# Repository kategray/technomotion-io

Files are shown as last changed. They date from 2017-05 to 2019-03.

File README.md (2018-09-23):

# Technomotion-IO

## Home of Tech-IO and the GHETT-iO

For documentation, see [https://ghett.io/](https://ghett.io/), or the
[docs/](docs/) folder.

This project is licensed under the [WTFPL 2.0](COPYING) license.  A license
is hereby granted to you to "just DO WHAT THE FUCK YOU WANT TO.".

This project is also available under the [MIT](COPYING) license.

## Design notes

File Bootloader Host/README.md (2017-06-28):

Bootloader host for updating GHETT-iO devices

CyUSB.dll is Copyright 2011, Cypress Semiconductor

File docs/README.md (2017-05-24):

# Technomotion IO Emulator

## Description
Dancing stage games are a popular form of entertainment in Japan, and in the United States.  This board provides I/O functionality for a simulated arcade environment.

## Background
### Hardware
Machines generally fall into three categories - four, five, and eight panel.

#### 4 Panel Machines (e.g. Dance Dance Revolution, In The Groove)
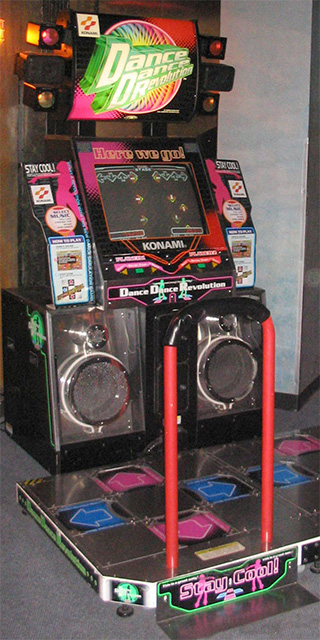
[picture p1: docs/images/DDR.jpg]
Dance Dance Revolution Machine


These games feature four arrows - Up,Down,Left,Right.  The center panel is usually non-functional, and is used as a place to stand.

#### 5 Panel Machines (e.g. Pump It Up)
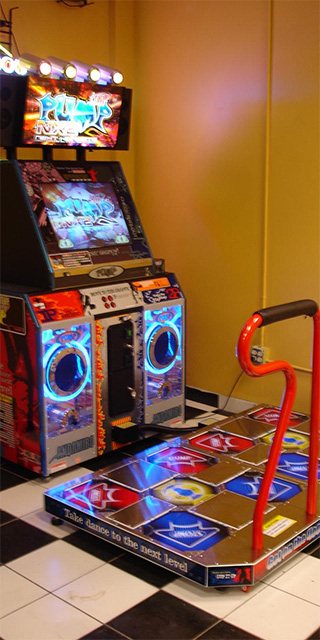
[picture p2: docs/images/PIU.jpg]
Pump It Up


Pump it up features 5 dance panels - a center panel and the 4 corners.  The center panel is functional, and players stand between the arrows when resting.

#### 8 Panel Machines (e.g. Technomotion)
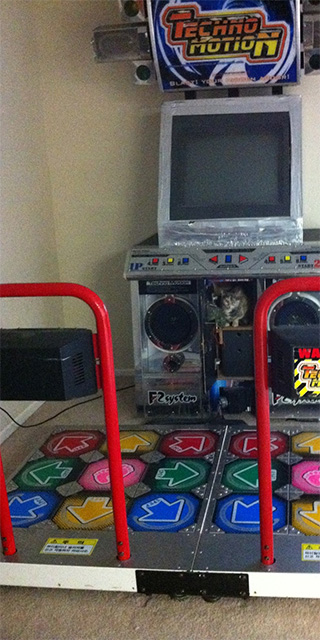
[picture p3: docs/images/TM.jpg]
TechnoMotion


TechnoMotion features a 9 panel stage, but lacks a 9 panel mode.  Instead, the game can be switched between 4 panel, 5 panel, and 8 panel (all panels except for the center), even while the game is playing.

### Emulation
Arcade machines (while new) typically cost $10,000 USD or more. They are difficult for people to use in their home due to the size and the weight.

StepMania is an open-source reimplementation of dancing stage games for home computers.  It features a flexible LUA-based scripting and theme engine, as well as support for emulation of the most popular play formats.

In general, dancing stage games follow a standard format.  A series of arrows is displayed on the screen, typically scrolling from bottom to top.  At the top of the screen a set of matching arrows are visible, and when the arrow at the top matches the arrow in the move list, the player is supposed to press the corresponding arrow.  Players receive points for proper presses, depending on how accurately their timing is.  Extra steps are generally not penalized.

### Hardware

#### Konami (Dance Dance Revolution)

Any discussion of Dancing games would be remiss if it did not start with Konami, the company largely responsible for the creation of the genre.

Konami is a Japanese entertainment company, and their Dance Dance Revolution game is highly influenced by the culture and environment which birthed it.  The game capitalized on the popularity of the J-Pop genre, as well as the popularity of English in Japan, leading to a game in which the text is mostly Japanese, but the dialog is all in English.  Songs are a fusion of Japanese and American songs, helping lead to the popularity of Japanese arcade machines in the US.

Being a Japanese game company, they developed for the popular systems of the time.  Working closely with Sony, they were able to adapt the processor from the popular PlayStation console to a custom PCB.  This allowed them to use largely the same game for home use and Arcade machines.  By producing a generic "playstation arcade version", they were able to keep the hardware largely the same (the System 573 platform), while producing I/O boards that could be used for different purposes.  Later versions of the arcade platform would simply put a Playstation 2 in an enclosure.

As a Japanese company, they tended to follow Japanese standards.  Their arcade machines follow the JAMMA (Japan Amusement Machine and Marketing Association) standards, and the Dance Dance Revolution machines are no exception.  JAMMA connectors are designed to permit arcade PCBs to easily move from one machine to another, and while the unique needs of the DDR machines (lights and cabinet outputs) necessitate additional connectors that make moving the PCB impossible, they still chose to follow the standard.

As is typical for arcade machines, JAMMA compliant power supplies feature +12v, +5v, and -5v rails.  +5v was chosen due to the use of CMOS logic signal voltage levels, and -5v is used in a few machines to drive op amps (generally for audio).  12v is used to drive lights, fans, etc., and reduces the line losses for the same wattage.

Inputs are active-low, which simplifies the handling and debouncing of inputs.  The input is brought high with the use of a pull-up resistor, and the normally open input is connected to ground.  A capacitor is used to keep the input high for a period of time after the switch is connected, and a Schmitt trigger serves to provide hysteris, leading to a very clean output.  Inverting Schmitt triggers are generally used to provide an active-high input to microcontrollers.

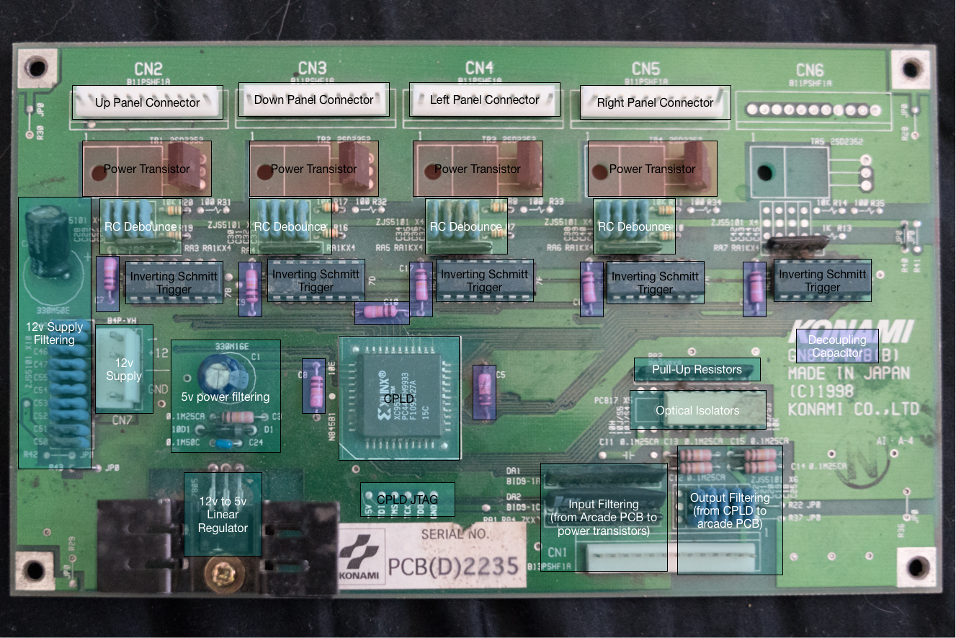
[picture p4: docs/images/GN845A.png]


Konami's design emphasized component reuse, and low EMI.  As such, they used a large number of 3 terminal EMI filters (ZJS5101), which combine the functions of both capacitors and inductors, providing an effective low-pass filter to reduce harmful RF interference.  The use of a linear voltage regulator, while less efficient, also served to avoid high speed switching noise.  Being a Japanese company, JST connectors were used.

The CPLD used (XC9536) provided for high-speed input handling.  Each panel contains 4 pressure-sensitive sensors, which are fed to Hex Schmitt Inverters.  The output from this is fed into the XC9536, which combines the inputs from each panel into a single output which is fed to the JAMMA harness.  Additionally, for testing, the CPLD can be placed into a mode where each sensor is individually addressable (to determine if sensors are stuck or failing to fire), and accessed via low speed RS232.  The use of the CPLD enables response times of several milliseconds, important for timing in rhythm-based games.  

Each panel has four inputs (one for each sensor), and an output (used to light the panel).  The IO board is designed to be extensible, and features support for an additional fifth input.  The output is driven using an NPN power transitor to switch the 12v supply.  

Signals from the stage PCB to the arcade PCB are optically isolated, cleaned up with a capacitor, and an EMI filter.  EMI coming from the system PCB to the stage PCB is less of an issue, and power surges more so.  As such, signals coming from the stage PCB are connected to two diode arrays (positive and negative) that serve as voltage clamps, protecting the NPN power transistor from voltages that exceed it's specifications by clamping them.

The board is responsible for its own conversion from 12v to 5v.  Although the system power supply is capable of producing a 5v supply, and linear voltage regulators are rather inefficient at this range, it provides a very clean and responsive supply.  Four separate capacitors are used (at different values) in order to ensure a very high speed response to power fluctuation.

#### Andamiro (Pump It Up)
As DDR was intended for use in JAMMA-Compatible arcades, as well as for the PlayStation, the game was largely limited to 4 direction inputs.  As such, Konami's design patents also extended to 4 directional inputs.

Pump It Up was built as a 5 panel game in part to get around the design patents.  By using diagonal arrows, and a center panel, they were able to avoid patent infringement.

#### Roxor Games (In The Groove)
Around 2004, Roxor Games came out with In The Groove, a game designed to adress the stagnation in the dance game marketplace.  Roxor contacted the authors of the open-source StepMania game, and were able to get it relicensed.  They partnered with Andamiro to produce a line of arcade cabinets that featured StepMania in a 4 panel configuration, with new songs and features.

Additionally, they produced a line of upgrade kits for existing Dance Dance Revolution arcade machines.  This led to a lawsuit for infringement of design patents that ultimately bankrupted them and led to a settlement in which Konamy received all rights to the In The Groove intellectual property.

The ITG-IO, unlike the hardware produced by Konami is designed to be cheap.  By using commodity desktop computers, they were able to position themselves as a very low cost upgrade.  RF emissions were high, and the lack of a common ground between the PC and the arcade power supply would often lead to problems, but for arcade owners facing dwindling returns on their hardware, it was a cost-effective solution.

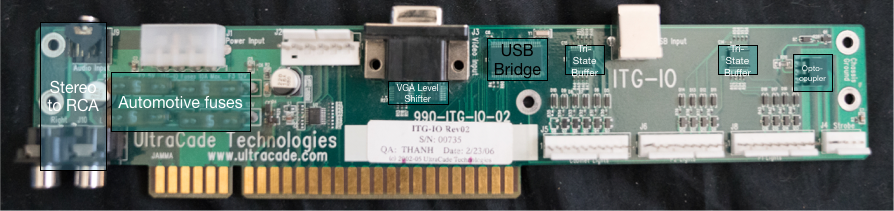
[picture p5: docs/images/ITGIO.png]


Roxor partnered with UltraCade Technologies to produce an IO board that permitted the adaptation of standard PCs to arcade machines.  It features a single optically-isolated output (to drive the neon lights), and the smallest possible number of inputs required.  As such, it ignores the second coin counter, coin lock functionality, buttons 1 and 4 of player input, etc.  Service and Test are combined into a single input.  Only VGA is supported, as the translation is more straightforward - 0.7v PC levels are amplified to 5v arcade levels, and the ITG-IO combines the separate RGB component sync signals into a single composite sync (as required by the JAMMA specification).

The ITG-IO does low-side switching, tristating the outputs with field effect transistors.  It features two USB endpoints, and it's low number of inputs and outputs allows packets to be 2 bytes in length.

Audio is handled by a simple passthrough 1/8 inch stereo to RCA adapter, intended for use with the DDR cabinet's audio amplifier.  Inputs come from the JAMMA connector, and outputs go to dedicated output connectors.

## Board Purpose

There are plenty of hardware solutions at present for getting four panel input to PC.  PS2 dance pads are widely available, along with a plethora of PS2 to USB adapters.  There are even a few options for output control, with devices like the Minimaid making it possible to replicate the functionality of the ITG-IO in placing a standard PC into a standard DDR cabinet.

Additionally, there are solutions out there for 5 and 8 (or 9) panel inputs.  Precision Dance Pads manufacturers dance pads in 4, 5, 6, or 9 panel configurations.

Unfortunately, where these solutions tend to fall short is outputs.  If someone wishes to build their own arcade machine, they are limited in the number of outputs they can have, and their ability to drive the lights on a cabinet, and in the pad.

The Technomotion IO emulater (Tek-IO) is designed to solve these issues.

## Theory of operation
Modern microcontrollers have significantly more analog IO functionality than previous generation chips.  The Cypress Programmable System on Chip (PSoC), for example, has the ability to do high-fidelity, adjustable PWM and software-defined debouncing.

Tek-IO is designed to handle all of the inputs and outputs necessary to construct any kind of dance control scheme.  It features the following benefits compared to existing solutions:

* Configurable analog I/O permits games (or players) to adjust the sensitivity
* Per-sensor configuration, permitting automatic adaptation to worn pads
* Automatic compensation for stuck or low-responsive pads
* Able to drive modern tricolor LEDs, permitting pads to change color depending on game mode or settings
* Permits the use of colored LEDs for cabinet lights and buttons
* Supports the use of multiple coin inputs (for example, a bill validator and a coin acceptor)
* Supports separate service, and courtesy credit input (useful for hardwired keyed momentary switches)
* Supports five buttons per player, allowing the use of DDR controls (left, right, start), DDR X (UDLR, Center), Technomotion (4 panel, 5 panel, 8 panel, Select, Start) and In The Groove (Left, Right, Up, Down).
* Programmable firmware permits the board to be reconfigured to different control schemes
* Implementation of the HID gamepad protocol enables easier integration
* A single board handles both stages, avoiding the need for separate power supplies
* Higher efficiency power supply reduces heat, and prolongs component life
* Ability to read individual sensors (using a propreitary interface)

Tek-IO presents itself to the operating system as a composite device with two separate 16-button joysticks, as well as offering USB endpoints for light control.  The use of two separate joysticks avoids issue with older versions of Linux experiencing memory corruption issues when using HID gamepads with more than 16 buttons.

## Inputs (Default configuration)
| Input | Description | Input |
| --- | --- | --- |
| P1 U, D, L, R | Player 1 Pad Up, Down, Left, Right | J1 B1-4  |
| P1 UL, UR, LL, LR | Player 1 Corners: UpperLeft, UpperRight, LowerLeft, LowerRight | J1 B5-8  |
| P1 Panel U, D, L, R | Player 1 Cabinet Up, Down, Left, Right | J1 B9-12 |
| P1 Center | Player 1 Pad Center panel | J1 B13 |
| P1 Panel Start | Player 1 Cabinet Start Button | J1 B14 |
| Coin 1 | First coin acceptor | J1 B15 |
| Service | Arcade machine service mode | J1 B16 |
| P2 U, D, L, R | Player 2 Pad Up, Down, Left, Right | J2 B1-4  |
| P2 UL, UR, LL, LR | Player 2 Corners: UpperLeft, UpperRight, LowerLeft, LowerRight | J2 B5-8  |
| P2 Panel U, D, L, R | Player 2 Cabinet Up, Down, Left, Right | J2 B9-12 |
| P1 Center | Player 1 Pad Center panel | J1 B13 |
| P2 Panel Start | Player 2 Cabinet Start Button | J2 B14 |
| Coin 2 | First coin acceptor | J2 B15 |
| Courtesy Credit | Arcade machine courtesy credit | J2 B16 |

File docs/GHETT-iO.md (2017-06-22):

# GHETT-iO Input/Output board

## Description
The GHETT-iO ("Ghetto IO") board is the easiest way to get input from a dance pad to a computer.  It is based on the [CY8CKIT-059][] PSoC prototyping kit.

## Philosophy
There are a variety of I/O solutions available for dance machines, however, it
can be difficult (and expensive) to replace failed parts.  Many of the boards are
designed to work only in an arcade cabinet; they rely upon external power supplies to
function.

The Cypress PSoC 5LP is a modern microcontroller with Full-Speed USB support, 
programmable logic capabilities, and a fast clock speed.  It's ARM-based, and has
a free manufacturer-supported toolchain [PSoC Creator][] available to download.

The company that produces the PSoC line of chips, [Cypress Semiconductor][] has made
available a $10 prototyping kit.  This kit includes a detachable programmer, and 
approximately 44 usable I/O pins (depending on configuration).  As the PSoC contains
internal input protection (diode clamps), as well as configurable pull-ups and pull-
downs, it is possible to handle all of the IO required for a standard DDR pad with
a single chip.

To assemble a GHETT-iO, one need only the kit from Cypress, reasonable soldering
equipment and skills, and the appropriate headers (if any).  The use of the standard
0.1 inch pitch and a DIP-style layout ensures that the board is directly compatible
with both breadboards and the DDR connectors.

The GHETT-iO is easy to assemble, and open source.  This should help ensure avail-
ability for the foreseeable future.

## Photos
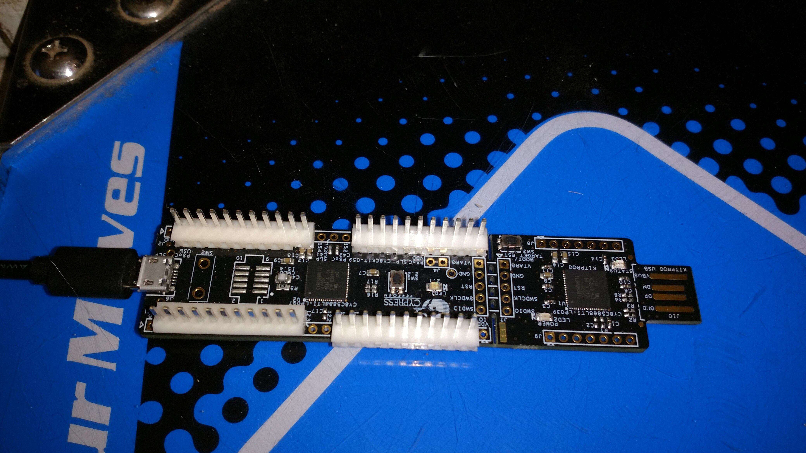
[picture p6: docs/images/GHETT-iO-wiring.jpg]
Connected GHETT-iO

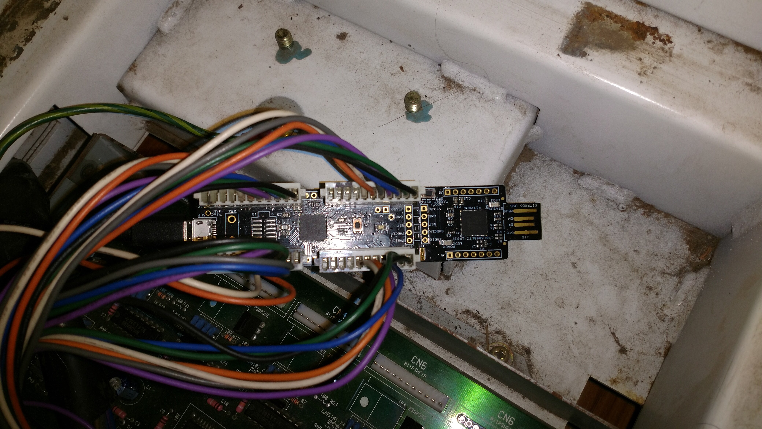
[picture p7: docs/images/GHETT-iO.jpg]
Bare GHETT-iO


[CY8CKIT-059]: http://www.cypress.com/documentation/development-kitsboards/cy8ckit-059-psoc-5lp-prototyping-kit-onboard-programmer-and

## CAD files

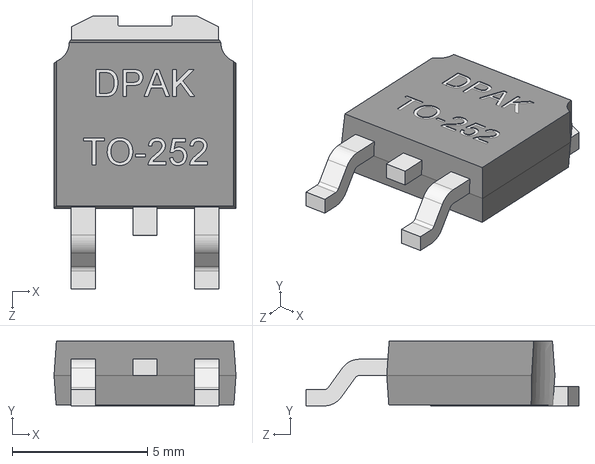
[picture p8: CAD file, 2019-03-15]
Light Board/3d/DPAK_TO-252AA.step
6.73 x 2.40 x 10.1 mm

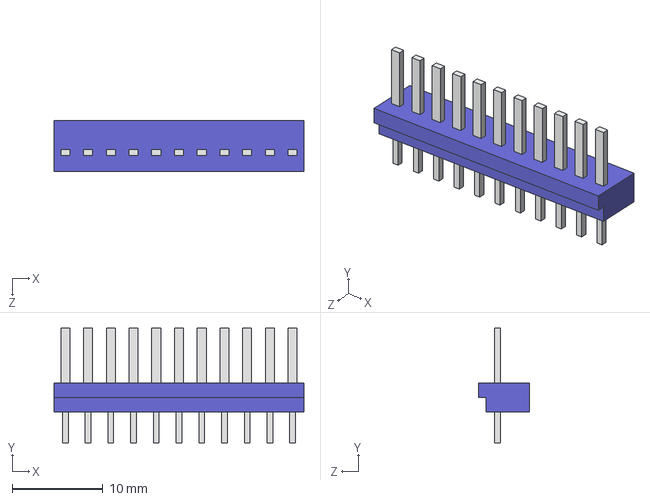
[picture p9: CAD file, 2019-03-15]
Light Board/3d/B11P-SHF-1AA.STEP
27.5 x 12.6 x 5.60 mm

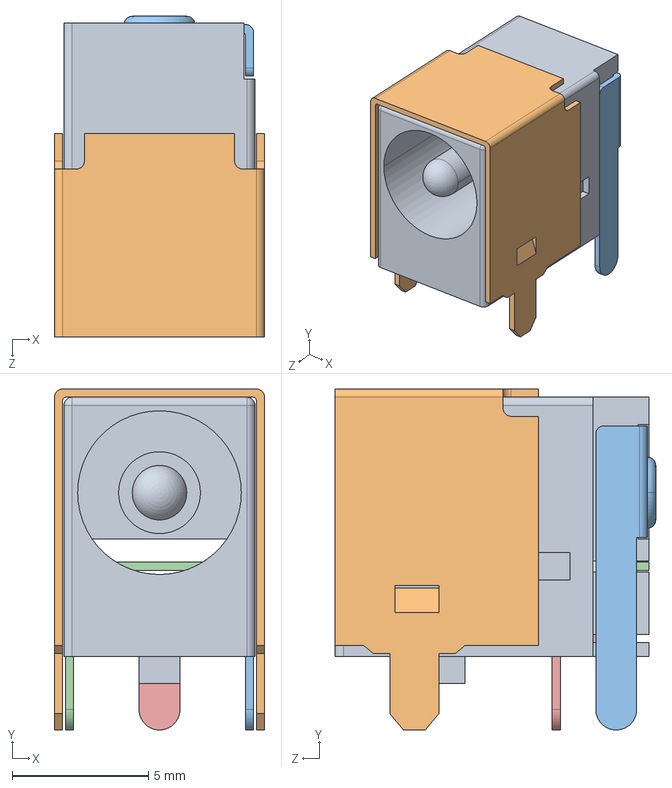
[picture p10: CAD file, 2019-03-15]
Light Board/3d/CUI_PJ-047AH.step
7.70 x 12.5 x 11.8 mm

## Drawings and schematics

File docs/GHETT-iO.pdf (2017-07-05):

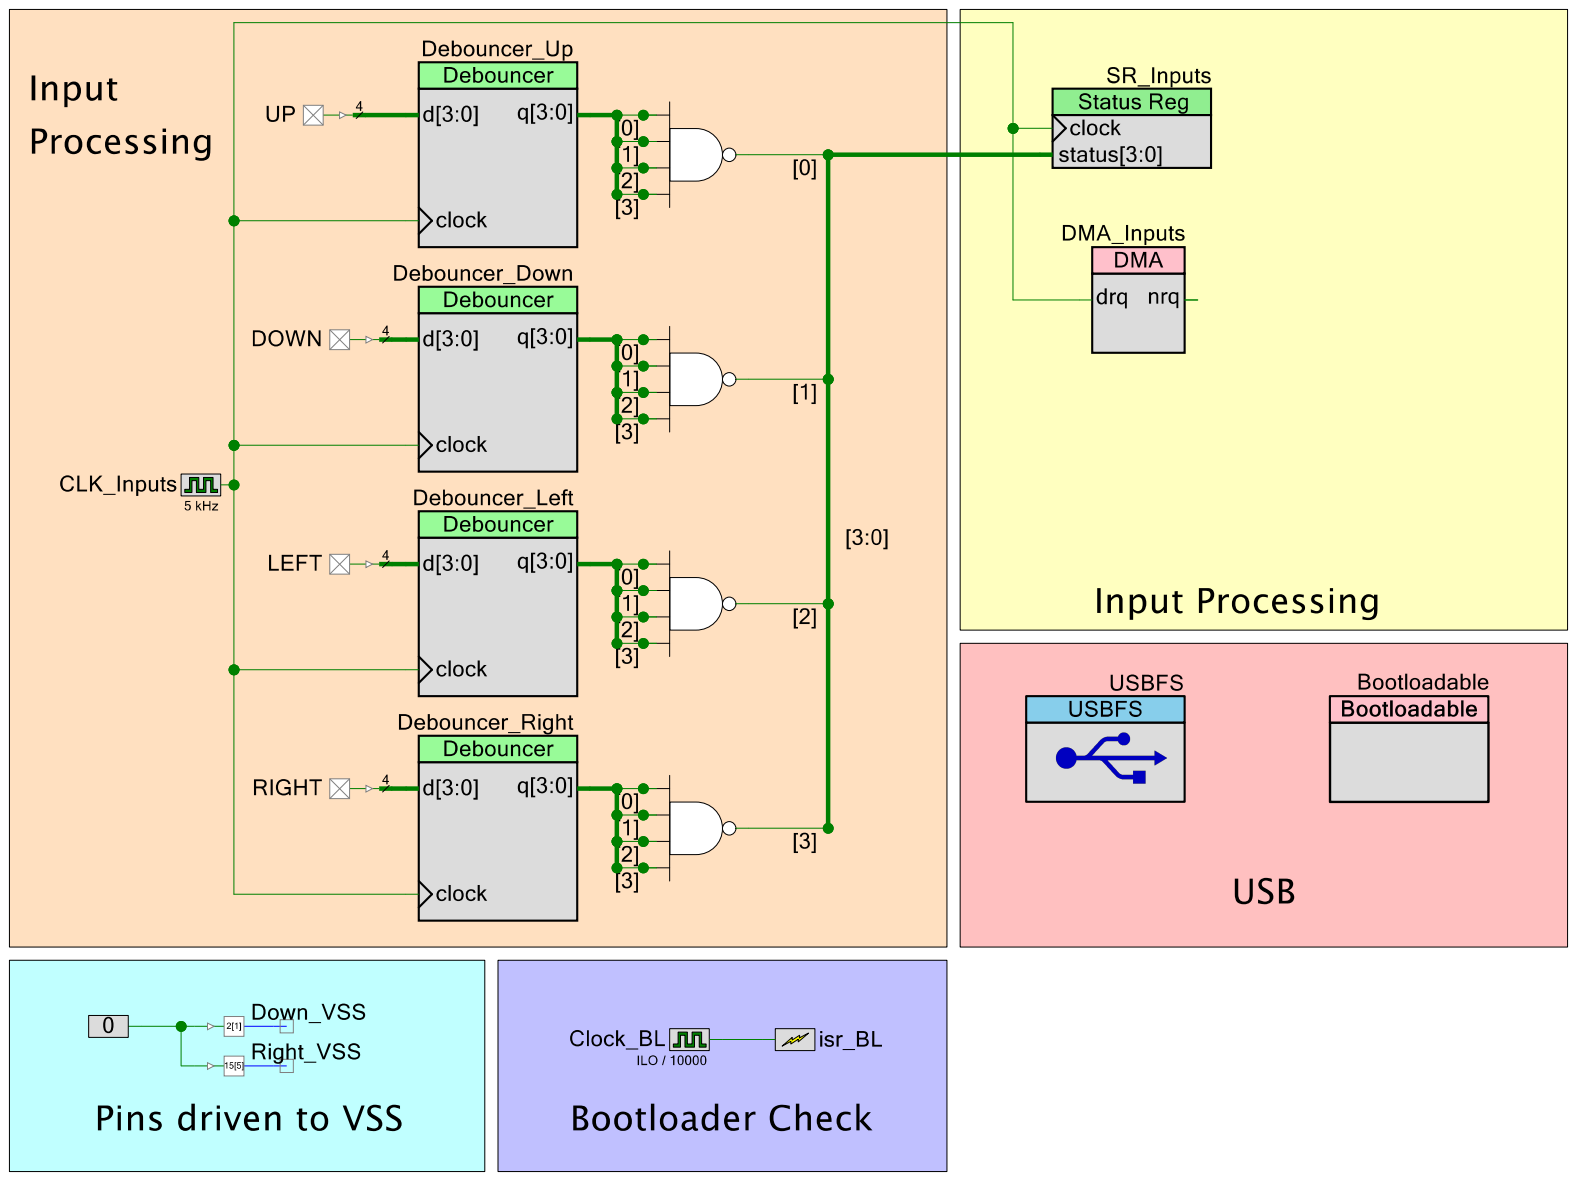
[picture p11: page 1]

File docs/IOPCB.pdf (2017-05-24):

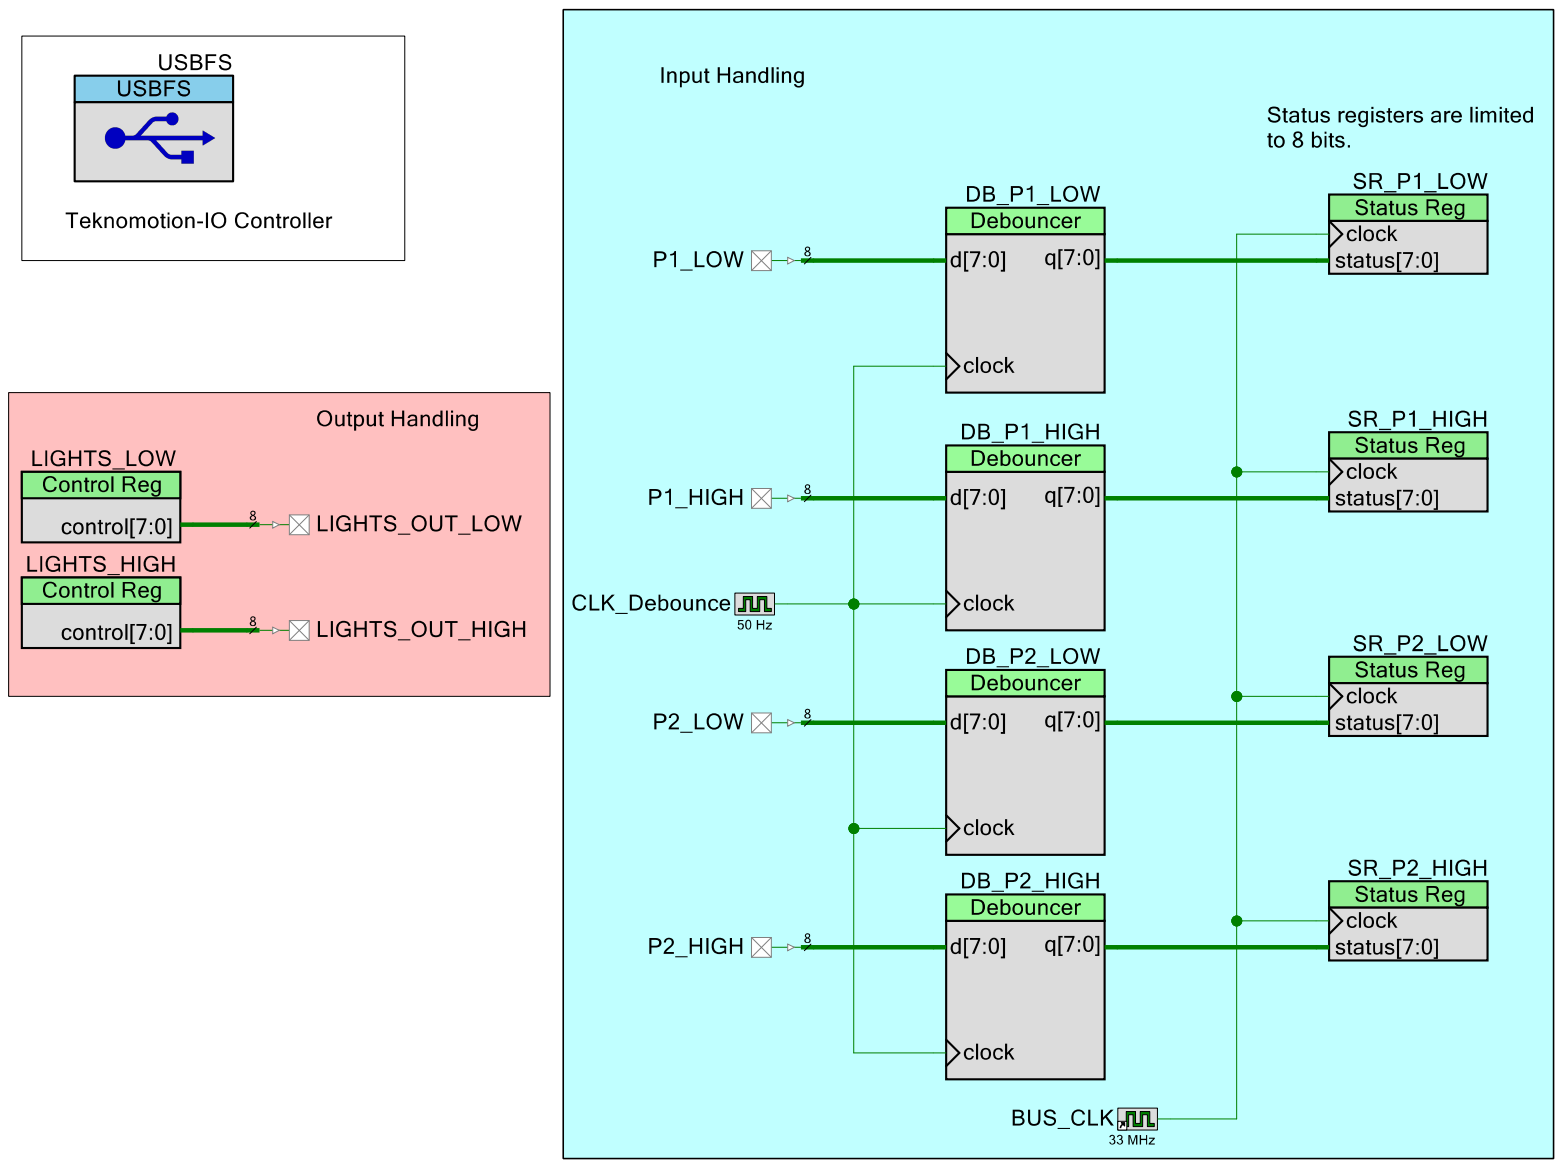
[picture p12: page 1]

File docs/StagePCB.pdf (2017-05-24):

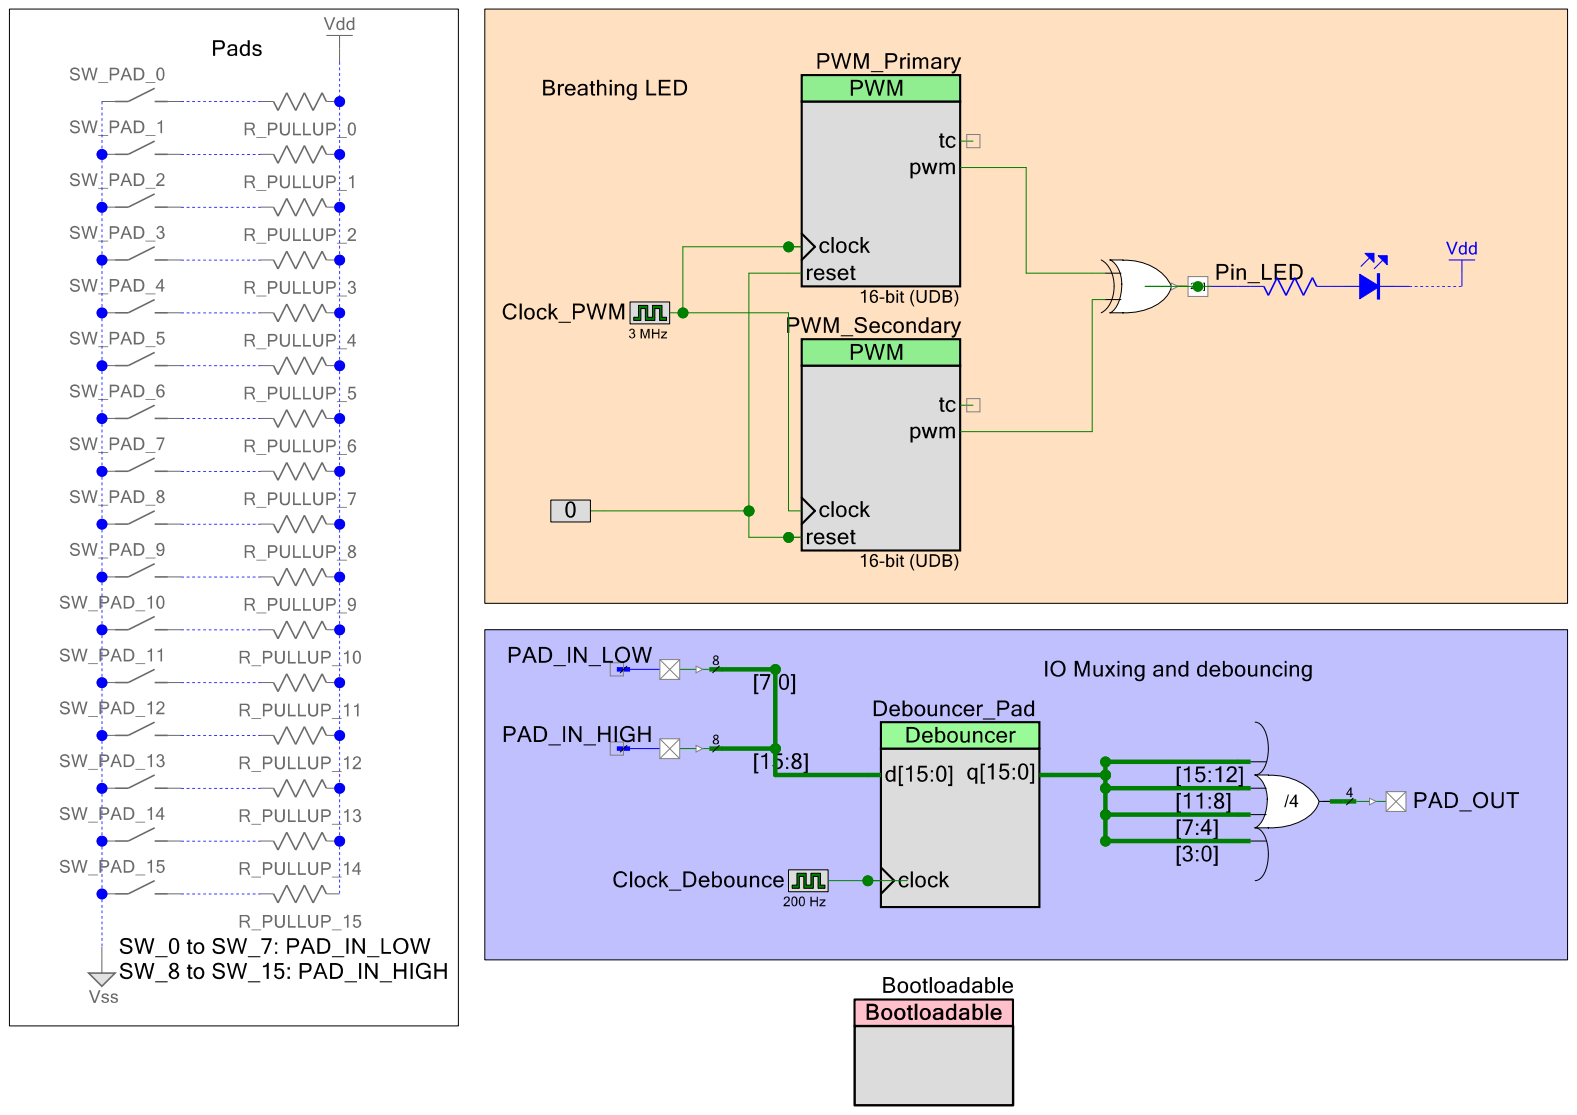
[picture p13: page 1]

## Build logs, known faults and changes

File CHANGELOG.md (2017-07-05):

2017-06-21  v1.0 Kate Gray  <opensource@codebykate.com>

    * Initial Release

2017-06-28  v1.1 Kate Gray  <opensource@codebykate.com>

    * Added a bootloader for updates using USB

    * Increased debounce poll rate

2017-07-04  v2.0 Kate Gray  <opensource@codebykate.com>

    * Switched to Direct Memory Access and ISRs for minimum latency

    * Added option to see firmware version of current GHETT-iO

    * Further increased debounce poll rate

    * Address issue where device resets when used in a pad

    * Change pin configuration to support future accessories

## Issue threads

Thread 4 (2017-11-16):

Linux Input

concubidated, 2017-11-16:
The Linux Event handler does not work with the IO boards due to the terrible check it does to see if something is a joystick.

It checks for X axis, throttle and wheel.
https://github.com/stepmania/stepmania/blob/5_1-new/src/arch/InputHandler/InputHandler_Linux_Event.cpp#L146

To get these to work in SM you need to add the LinuxJoystick driver to your input devices.

In Preferences.ini
```InputDevices=LinuxEvent,X11,LinuxJoystick```

Figured this info could help someone else.

kategray, 2019-02-02:
Just came across this.  Eww.

I'll add a dummy throttle and wheel if that's necessary to get this working.

kategray, 2019-03-26:
@concubidated Is the HID input driver not supported?

kategray, 2020-04-27:
Closing this as I never got a response.

Closed 2020-04-27.

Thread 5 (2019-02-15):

No input on boot.

MrAshDarksideTM, 2019-02-15:
Whenever I boot the system with a Ghett.io plugged in, it is seen in Windows game controllers, but no inputs work.  If I physically disconnect and reconnect the USB cable, they work fine.  Is there anyway to address that as I'd like to do a fairly clean, cable hidden install.  Problem is duplicated in Windows 7, Windows 10, as well as Ubuntu.  I've tried using Devcon to refresh the USB ports via software but no luck there.  Thanks!

ianklatzco, 2019-02-15:
Are you using Stepmania?

MrAshDarksideTM, 2019-02-15:
Yes.

ianklatzco, 2019-02-15:
Simply Love has an IO test screen that lists recognized devices. Does the Ghett-io show up there:
* right after you boot, before you unplug/replug it?
* after you unplug/replug it?

MrAshDarksideTM, 2019-02-15:
Yeah, they both show up as J1 and J2.  No response in stepmania, but unplugging them and plugging them in they work fine.

kategray, 2019-02-15:
I will have time to look at this next week.  I likely can't get the root issue fixed without being able to reproduce it, but I have a version of the firmware I'm working on that auto-resets when USB breaks.
 Depending on what's wrong, that may or may not fix the issue.

@MrAshDarksideTM Can you try doing a firmware update using the utility?

https://github.com/kategray/technomotion-io/releases/download/2.0/Firmware.Upgrader.zip

The firmware updater does a reset as part of it's normal operation.  I'm curious if booting and updating, running through the bootloader than getting reset fixes the issue.  If so, I can also add a reset command to the firmware at the very least.

MrAshDarksideTM, 2019-02-15:
Updated firmware on both of them and they became immediately responsive right after, so it seems that reset does the trick for sure.  Goes back to being unresponsive after a restart of the PC though, but definitely promising. :)

kategray, 2019-02-16:
Does it do it on a full power off cold boot?

MrAshDarksideTM, 2019-02-16:
Yeah, same results weather restart, or cold boot.

kategray, 2019-03-13:
@MrAshDarksideTM can you try the v3.0 beta release, please?

MrAshDarksideTM, 2019-03-13:
For sure, I'll fire it up after work today.

MrAshDarksideTM, 2019-03-13:
So far it seems to have fixed the problem!

kategray, 2019-03-14:
Closing this as fixed unless you have further problems.

Closed 2019-03-14.

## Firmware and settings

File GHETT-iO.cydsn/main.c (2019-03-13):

/**
 * GHETT-iO
 *
 * Handles a single DDR pad, using only a PSoC 5LP dev board. (CY8CKIT-059)
 *
 * The CY8CKIT-059 development board is a cheap I/O board based on the PSoC 5LP
 * line of microcontrollers from Cypress Semiconductor.  These boards combine
 * an ARM cortex M3 CPU with programmable logic and analog capabilities.
 *
 * The CY8CKIT-059 is a cheap ($10) board with the same pitch (0.100in) as the
 * connectors used by the stage PCB in Dance Dance Revolution arcade machines.
 * Due to the failure of many stage PCBS (as well as the lack of updates to
 * the platform after 2002), many users wish to connect their dance stages to
 * modern desktop computers.  The programmable logic fabric present in the PSoC
 * enables very high-speed input processing, as it is possible to debounce and
 * invert the (active low) inputs.  Built-in input protection (diode clamps to
 * VCC and ground on all inputs), as well as built-in buffers and pull-up
 * resistors permit the PSoC to be configured to handle all of the inputs
 * without the need to add any additional hardware to the board except
 * connectors.
 *
 * Copyright 2017, Kate Gray
 *
 * This work is free. You can redistribute it and/or modify it under the
 * terms of the Do What The Fuck You Want To Public License, Version 2,
 * as published by Sam Hocevar. See http://www.wtfpl.net/ for more details.
 */
#include <project.h>
#include <stdio.h>
#include "main.h"

// Input data structures
#include "io.h"

// At the moment, we have only one USB descriptor.
// Future versions (multi-pad) will need to support additional descriptors.
#define USBFS_DESCRIPTOR 0u

// Endpoints 
#define IN_ENDPOINT   1u    // Inputs

#ifdef Bootloadable_GET_RUN_TYPE
// Bootloader ISR Definition
CY_ISR_PROTO(bootloaderISR);

// Bootloader invocation flag
CYBIT runBootloader = 0;
#endif

// Holds player input
INPUTS input;

int main()
{
    // DMA channel identifier.  DMA channels are used to instruct the Peripheral Hub (PHUB) to transfer data.
    // Chanels hold one or more Transaction Descriptors, which must all have the same source and destination.
    uint8 DMA_INPUTS_Chan;
    
    // Transaction Descriptor.
    // Stores configuration for a DMA transfer.  Can be chained within a DMA channel.
    uint8 DMA_INPUTS_TD[1];
    
    // Allocate the DMA chanel, with bursts of 1 byte, and store the channel number
    DMA_INPUTS_Chan = DMA_Inputs_DmaInitialize(DMA_INPUTS_BYTES_PER_BURST, DMA_INPUTS_REQUEST_PER_BURST, 
    HI16(DMA_INPUTS_SRC_BASE), HI16(DMA_INPUTS_DST_BASE));
    
    // Allocate the transaction descriptor and configure it to copy from the peripheral (status register)
    // to SRAM.  We're only doing a single transfer at a time, and we aren't chaining, so go ahead and
    // disable the TD after completion, rather than calling the next TD.  Set the address to the global
    // input address.
    DMA_INPUTS_TD[0] = CyDmaTdAllocate();
    CyDmaTdSetConfiguration(DMA_INPUTS_TD[0], DMA_INPUTS_TD_TRANSFER_INDEFINITELY, 
        DMA_INPUTS_TD[0], DMA_Inputs__TD_TERMOUT_EN);
    CyDmaTdSetAddress(DMA_INPUTS_TD[0], LO16((uint32)SR_Inputs_Status_PTR), LO16((uint32)&input));
    
    // Configure our TD to be the first TD in the "chain" and enable it.
    CyDmaChSetInitialTd(DMA_INPUTS_Chan, DMA_INPUTS_TD[0]);
    CyDmaChEnable(DMA_INPUTS_Chan, 1);
    
    // Periodically update the lights.  A special sequence will enter the bootloader.
    isr_Lights_ClearPending();
    isr_Lights_StartEx(Check_Lights);
        
    // Configure the Status Register interrupts
    SR_Inputs_InterruptEnable();
    
    // Enable interrupts (macro for an inline ASM instruction)
    CyGlobalIntEnable;
    
    // Enable the watchdog timer to reset if this freezes
    CyWdtStart (CYWDT_1024_TICKS, CYWDT_LPMODE_DISABLED);
    
    // Zero out the player array.  This is really not needed, but it's still a good habit.
    // The reset interrupt (in CM3Start.c) calls the Start_C function which loops through all 
    // the defined sections, initializing memory from flash for predefined memory (constants, pre-
    // initialized variables).  Afterwards, it initializes the remainder of the memory with zeros.
    // On top of that, this is going to be initialized from the status register by DMA, and the
    // value is not particularly important.
    memset((uint8*)&input, 0u, sizeof(INPUTS));
    
    // Start up USB and wait for enumeration.
    USBFS_Start(USBFS_DESCRIPTOR, USBFS_5V_OPERATION);
    while (0u == USBFS_GetConfiguration())
    {  
        // Wait for USB to enumerate.  It can take a little while.
    }
    
    // The USBFS component is configured to use DMA with automatic buffer management, and USB is 
    // handled by the Serial Interface Engine (SIE). Timing on USB transfers is critical, so an 
    // arbiter is used to marshall requests from the SIE, the CPU, and the DMA interface, with priority
    // given to the SIE.
    // 
    // Due to the critical nature of the timing, it is not possible to configure the SIE to pull it's 
    // data directly from peripherals using the DMA bus.  Only memory to peripheral transfers (SRAM
    // to USB are supported.  We work around this by using SRAM as an intermediary.
    //
    // Because DMA is enabled, this function will automatically configure the USBFS_EP1 DMA channel (channel
    // 0) for transfers from SRAM to the SIE, starting at &input.  If DMA were disabled, this would instead
    // copy the data to a buffer, and it would be necessary to periodically fill the buffer.
    USBFS_LoadInEP(IN_ENDPOINT, (uint8*)&input, sizeof(INPUTS));
    
    // Prime the pump, starting a DMA transfer.  The buffer will be replenished by the endpoint exit callback
    USBFS_LoadInEP(IN_ENDPOINT, USBFS_NULL, sizeof(INPUTS));
    
    // Loop indefinitely
    for(;;) {
    }
}

CY_ISR(Check_Lights) {
    static uint8 trigger[FEATURE_BUFFER_LEN] = BOOTLOADER_TRIGGER;
    
#ifdef Bootloadable_GET_RUN_TYPE
    // Should we invoke the bootloader?
    if (!memcmp(FEATURE_BUFFER, trigger, FEATURE_BUFFER_LEN)) {
        // Clear the ISR
        isr_Lights_ClearPending();
        isr_Lights_Disable();
        
        // Run the bootloader
        Bootloadable_Load();
    }
#endif

    // Write the lights
    CR_Lights_Write(FEATURE_BUFFER[0]);
}

/*
 * Callback for when USB endpoint one is processed
 */
void USBFS_EP_1_ISR_ExitCallback() {
    // Is our USB buffer empty?
    if (USBFS_GetEPState(IN_ENDPOINT) == USBFS_IN_BUFFER_EMPTY) {
        // Re-arm the DMA to re-fill the buffer
        USBFS_LoadInEP(IN_ENDPOINT, USBFS_NULL, sizeof(INPUTS));
        
        // Reset the watchdog timer
        CyWdtClear();
    }    
}

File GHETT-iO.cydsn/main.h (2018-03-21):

/*
 * Copyright 2017, Kate Gray
 *
 * This work is free. You can redistribute it and/or modify it under the
 * terms of the Do What The Fuck You Want To Public License, Version 2,
 * as published by Sam Hocevar. See http://www.wtfpl.net/ for more details.
 */
#ifndef MAIN_H
#include <project.h>

#ifdef Bootloadable_GET_RUN_TYPE
// Bootloader check ISR
CY_ISR_PROTO(Check_Lights);
#endif
    
// The data from the USB feature is stored in a variable with a hard to read name
// Alias it to make it simple.
#define FEATURE_BUFFER USBFS_DEVICE0_CONFIGURATION0_INTERFACE0_ALTERNATE0_HID_FEATURE_BUF
#define FEATURE_BUFFER_LEN USBFS_DEVICE0_CONFIGURATION0_INTERFACE0_ALTERNATE0_HID_FEATURE_BUF_SIZE

// When we see this feature report, load the bootloader
#define BOOTLOADER_TRIGGER {0xDE, 0xAD, 0xBE, 0xEF, 0u}

// Defines for DMA_INPUTS.  Sets up a 1 byte burst from the Peripheral to SRAM
#define DMA_INPUTS_BYTES_PER_BURST 1                // DMA transfers should burst according to the TD
#define DMA_INPUTS_REQUEST_PER_BURST 1              // Automatically perform more bursts as needed
#define DMA_INPUTS_SRC_BASE (CYDEV_PERIPH_BASE)     // Base address for the source
#define DMA_INPUTS_DST_BASE (CYDEV_SRAM_BASE)       // Base address for the destination
#define DMA_INPUTS_TD_TRANSFER_INDEFINITELY 0       // Continue DMA indefinitely
    
#endif /* MAIN_H */

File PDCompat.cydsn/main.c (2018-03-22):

/*******************************************************************************
* File Name: main.c
*
* Version: 3.0
*
* Description:
*  This code example demonstrates USB HID interface class operation by 
*  implementing a 3-button mouse. When the code is run, the mouse cursor moves 
*  from the right to the left, and vice-versa.
*
*
* Related Document:
*  Device Class Definition for Human Interface Devices (HID)
*  Firmware Specification- Version 1.11
*
********************************************************************************
* Copyright 2015, Cypress Semiconductor Corporation. All rights reserved.
* This software is owned by Cypress Semiconductor Corporation and is protected
* by and subject to worldwide patent and copyright laws and treaties.
* Therefore, you may use this software only as provided in the license agreement
* accompanying the software package from which you obtained this software.
* CYPRESS AND ITS SUPPLIERS MAKE NO WARRANTY OF ANY KIND, EXPRESS OR IMPLIED,
* WITH REGARD TO THIS SOFTWARE, INCLUDING, BUT NOT LIMITED TO, NONINFRINGEMENT,
* IMPLIED WARRANTIES OF MERCHANTABILITY AND FITNESS FOR A PARTICULAR PURPOSE.
*******************************************************************************/

#include <project.h>

#define USBFS_DEVICE        (0u)

#define LIGHT_ENDPOINT      (1u)
#define LIGHT_DATA_LEN      (2u)

uint8 lightData[LIGHT_DATA_LEN] = {0u, 0u};


/*******************************************************************************
* Function Name: main
********************************************************************************
*
* Summary:
*  Wraps the OUT data coming from the host back to the host on a subsequent IN.
*
* Parameters:
*  None.
*
* Return:
*  None.
*
*******************************************************************************/
int main()
{
    unsigned int length;
    uint8_t buffer[9];
    
    CyGlobalIntEnable;
    
    /* Start USBFS operation with 5-V operation. */
    USBFS_Start(USBFS_DEVICE, USBFS_5V_OPERATION);
    
    USBFS_EnableOutEP(LIGHT_ENDPOINT);

    /* Wait for device to enumerate */
    while (0u == USBFS_GetConfiguration())
    {
    }

    for(;;)
    {
       /* Check if configuration is changed. */
        if (0u != USBFS_IsConfigurationChanged())
        {
            /* Re-enable endpoint when device is configured. */
            if (0u != USBFS_GetConfiguration())
            {
                /* Enable OUT endpoint to receive data from host. */
                USBFS_EnableOutEP(LIGHT_ENDPOINT);
            }
        }

        /* Check if data was received. */
        if (USBFS_OUT_BUFFER_FULL == USBFS_GetEPState(LIGHT_ENDPOINT))
        {
            length = USBFS_GetEPCount (LIGHT_ENDPOINT);
            if (length > sizeof(buffer)) {
                length = sizeof(buffer);
            }
            
            USBFS_ReadOutEP(LIGHT_ENDPOINT, buffer, length);
            
            // The first byte is part of the USB protocol.  The second byte is a command.
            // We want the third and fourth bytes.
            if (length > 2 && buffer[1] == 0xdd) {
                CR_PORT1_Write(~buffer[2]);
                CR_PORT2_Write(~buffer[3]);
            }            
        }

    }
}

/* [] END OF FILE */

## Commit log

2017-05-14 ITG-IO Improvements
    Switch to a single 32-button joystick to avoid issues with mapping
    order.
    Move lights endpoint to the same interface descriptor as the inputs
    endpoint, since HID makes an input endpoint mandatory for all HID
    devices.
    [main.c]
2017-05-24 Cleanup generated and temporary files Add bootloader and stage PCB files
2017-07-04 Switch to DMA for inputs
2017-07-04 v1.2 Firmware
    Increase poll rate
    Switch to DMA for minimum latency
    Update documentation
2017-07-05 Fix issue with simultaneous arrows and ISR
    Update Documentation
    [main.c]
2018-03-21 Clean-up and update boards
2018-03-22 Add light driver option
2019-03-15 Add beta light board
    [B11P-SHF-1AA.STEP, CUI_PJ-047AH.step, DPAK_TO-252AA.step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]
2019-03-15 Add missing schematic
    [Light Board.PrjPCB, Light Board.SchDoc]
